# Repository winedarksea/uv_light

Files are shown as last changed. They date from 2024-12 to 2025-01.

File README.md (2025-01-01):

# uv_light
Licence: CERN Open Hardware Licence Version 2 - Strongly Reciprocal

 Custom Sun Lamp / Full Spectrum Lamp
 
 Background writeup [here](https://syllepsis.live/2024/12/31/light-for-health-and-a-custom-sun-lamp/)

A heatsink is important. All 16 leds are too much, unfortunately.

Problem: the comparator circuit for voltage sensing doesn't work properly, and needs a look at.

Minor problem: there's one trace that is bridged by the heatsink here. Using a non conductive thermal pad between the pcb and heatsink solves that problem, or redesign.

Recommendation: add a switch to the UV circuit as well. Also perhaps use larger switches than those specced here if you intend to switch the active lights often.

Designed for:
* QLUV07EYGE
* JE2835 3V N CLASS FAR RED
* Samsung LM302N White, Cool 6500K 
* Samsung LM302N WARM WHT 2700K 1212
* GT PSLR31.13-LUMQ-T1T2-1-150-R18 LED DURIS S5 GREEN 540NM SMD

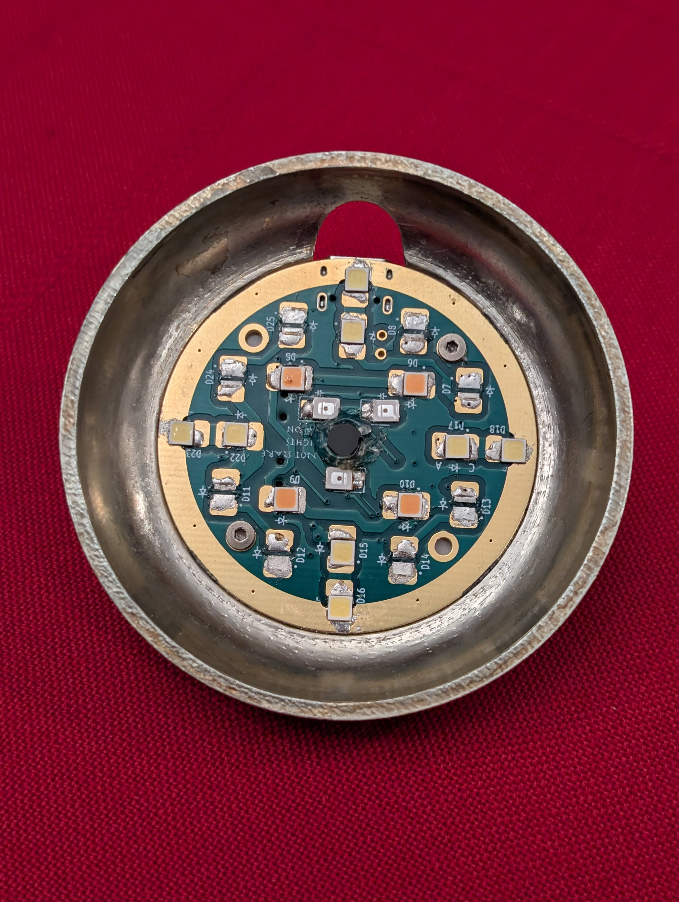
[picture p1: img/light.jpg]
plot


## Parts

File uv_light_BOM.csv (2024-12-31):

Designator | Value | Footprint | Vendor
C1, C2, C3, C4, C5, C6, C7, C8, C9, C10, C11, C12, C13, C14 | 1 uF 50V X5R | Capacitor_SMD:C_0603_1608Metric | C15849
C15 | 10 nF 50V X7R | Capacitor_SMD:C_0402_1005Metric_Pad0.74x0.62mm_HandSolder | C15195
D21 | SM712_SOT23 | Package_TO_SOT_SMD:SOT-23 | C32677
D26 | GI_LED | LED_SMD:LED_0805_2012Metric_Pad1.15x1.40mm_HandSolder | C2297
D27 | RI_LED | LED_SMD:LED_0603_1608Metric_Pad1.05x0.95mm_HandSolder | C2286
J1 | USB_C_Receptacle_USB2.0 | Connector_USB:USB_C_Receptacle_HRO_TYPE-C-31-M-12 | C165948
Q1, Q4, Q5 | AO3401A | Package_TO_SOT_SMD:SOT-23 | C15127
Q2, Q3 | P-Channel DFN-8 | PowerIC:TRANS_AONR21307 | C541711
R1 | 33 | Resistor_SMD:R_0603_1608Metric_Pad0.98x0.95mm_HandSolder | C23140
R2 | 10 | Resistor_SMD:R_0805_2012Metric_Pad1.20x1.40mm_HandSolder | C17415
R3, R11, R12 | 200K | Resistor_SMD:R_0402_1005Metric_Pad0.72x0.64mm_HandSolder | C25764
R4, R6 | 4.53K | Resistor_SMD:R_0603_1608Metric_Pad0.98x0.95mm_HandSolder | C321916
R5 | 10K | Resistor_SMD:R_0603_1608Metric_Pad0.98x0.95mm_HandSolder | C25804
R7 | 180 | Resistor_SMD:R_0603_1608Metric_Pad0.98x0.95mm_HandSolder | C22828
R8, R9, R13, R14 | 680 | Resistor_SMD:R_0805_2012Metric_Pad1.20x1.40mm_HandSolder | C17798
R10 | 2K7 | Resistor_SMD:R_0603_1608Metric_Pad0.98x0.95mm_HandSolder | C13167
SW1, SW2 | SW_SPDT | Button_Switch_SMD:SW_SPDT_PCM12 | C128955
U1 | HUSB238 | Package_DFN_QFN:DFN-10-1EP_3x3mm_P0.5mm_EP1.65x2.38mm | C7471904
U2 | LM393 | Package_SO:SOIC-8_3.9x4.9mm_P1.27mm | C7955
U3 | TL431DBZ | Package_TO_SOT_SMD:SOT-23 | C3113

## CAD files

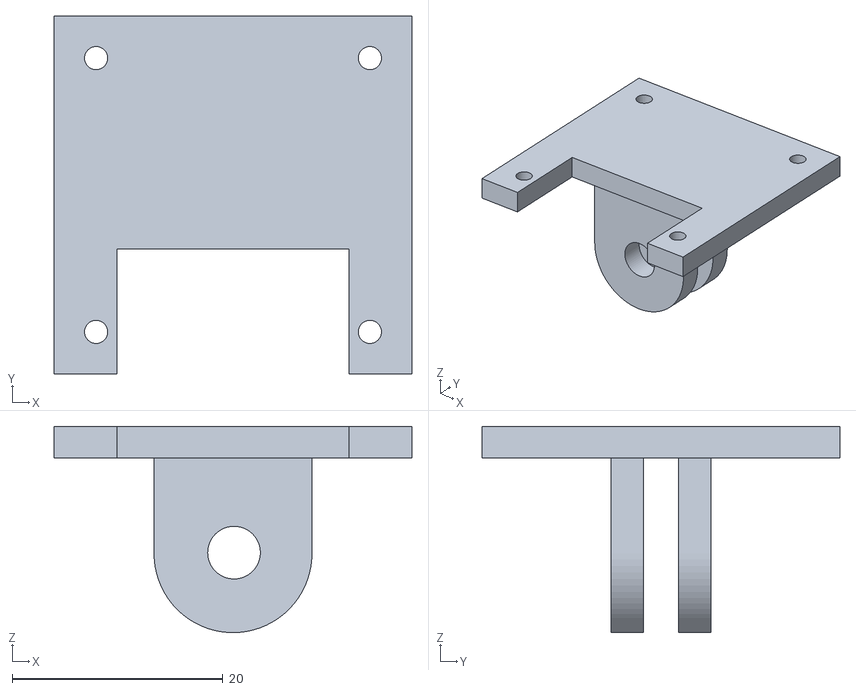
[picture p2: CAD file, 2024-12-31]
3d_files/GoPro mount for Reflector.stl
34.0 x 34.0 x 19.6

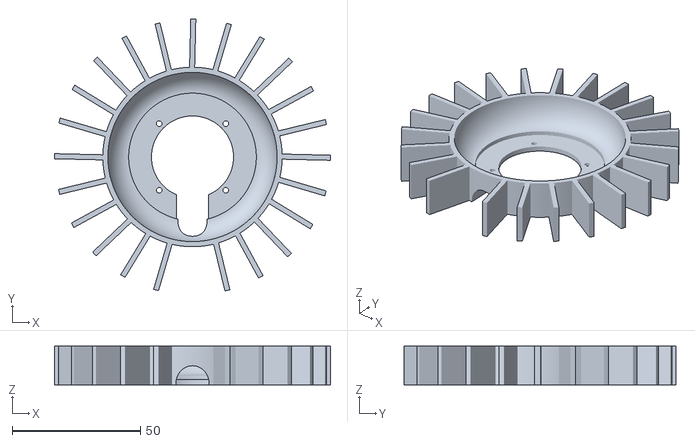
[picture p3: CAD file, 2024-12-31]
3d_files/UV Reflector with fins.stl
107.7 x 106.1 x 15.0

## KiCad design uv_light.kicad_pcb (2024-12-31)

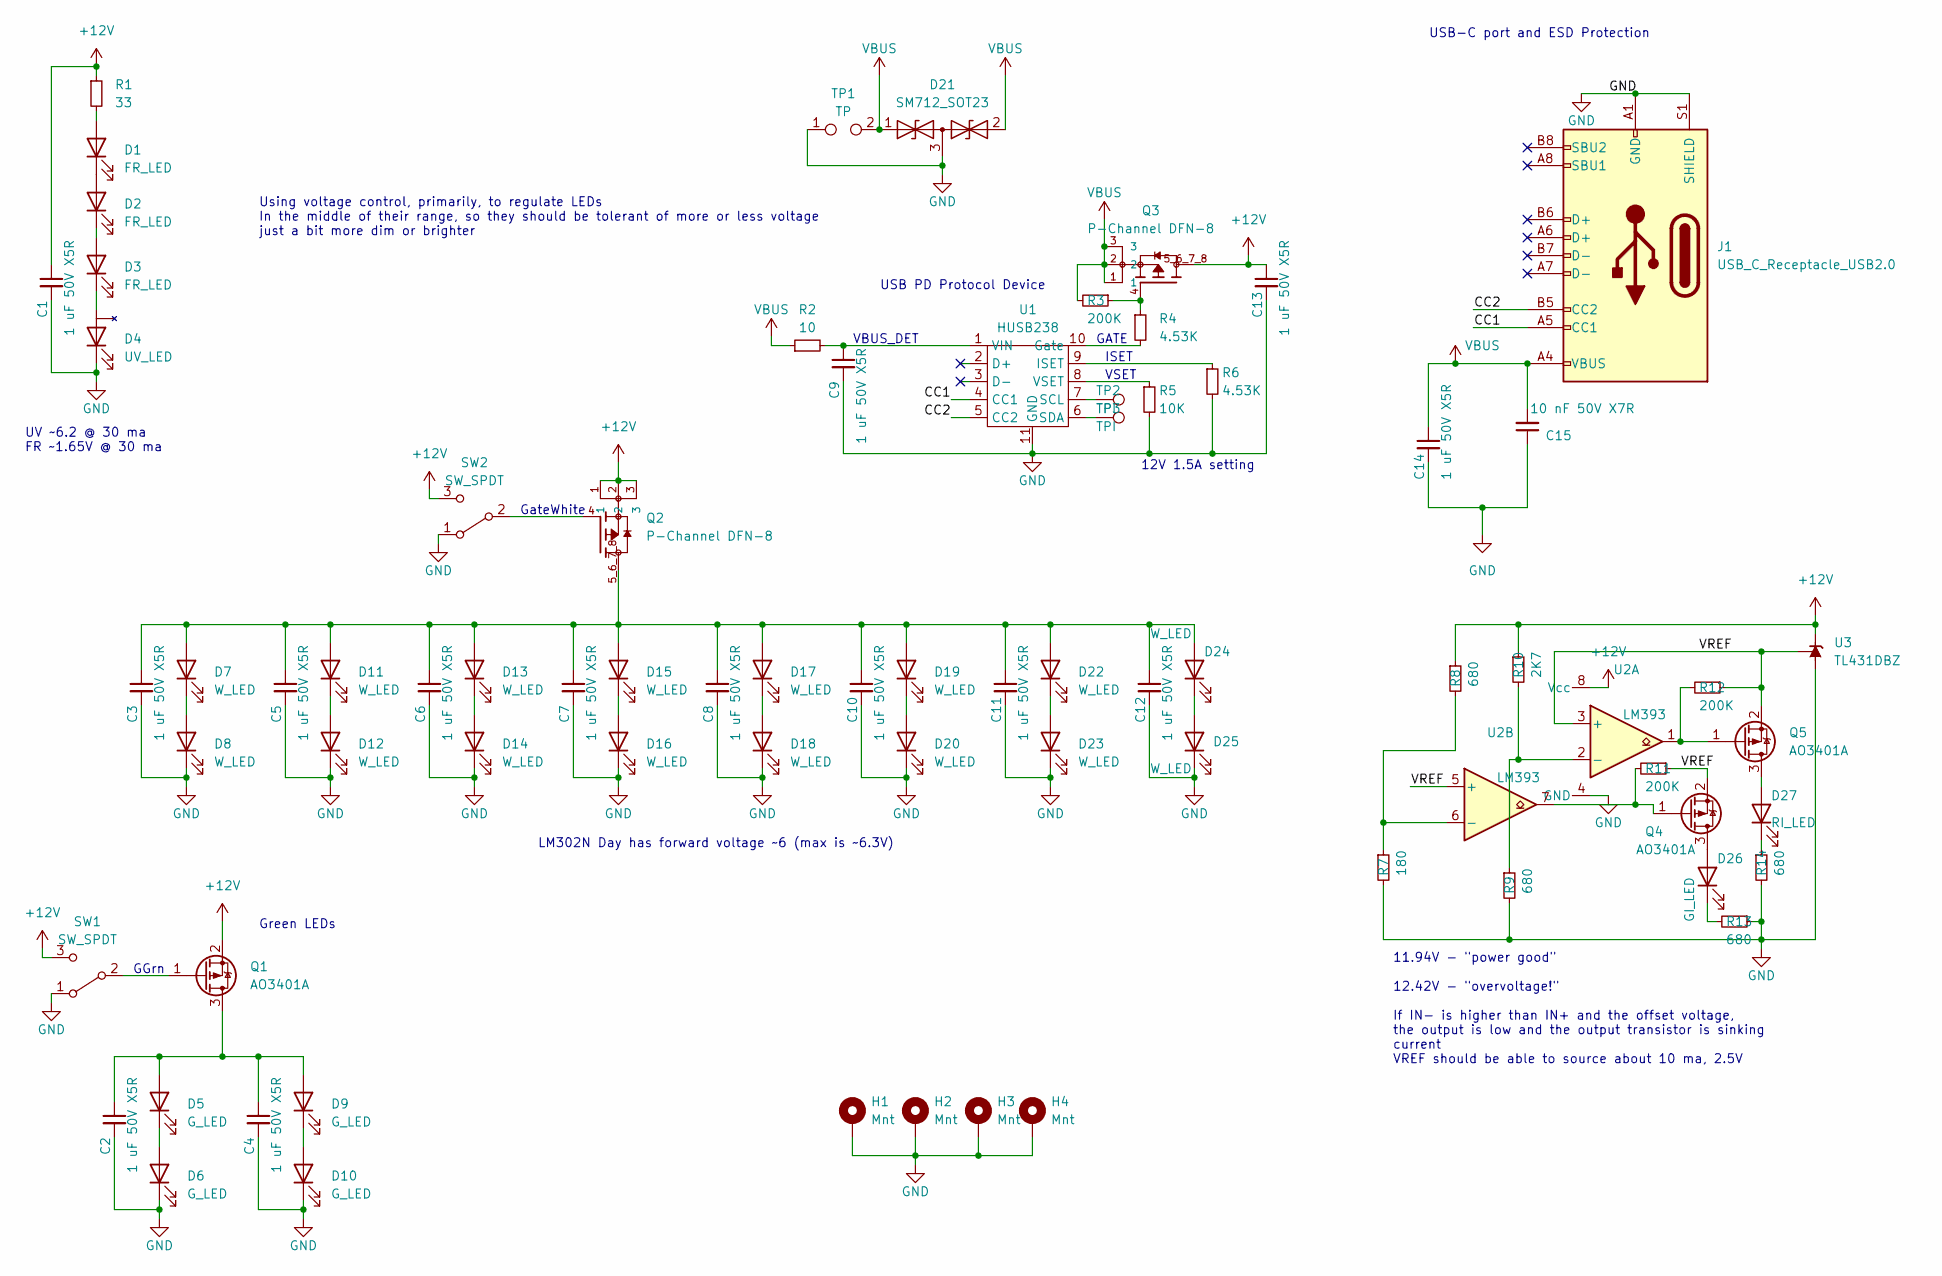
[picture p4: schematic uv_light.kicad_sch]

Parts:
C1, C2, C3, C4, C5, C6, C7, C8, C9, C10, C11, C12, C13, C14: 1 uF 50V X5R; C_0603_1608Metric
C15: 10 nF 50V X7R; C_0402_1005Metric_Pad0.74x0.62mm_HandSolder
D1, D2, D3: FR_LED; LED_PLCC_2835_Handsoldering
D4: UV_LED; LED_Cree-XHP35
D5, D6, D9, D10: G_LED; LED_SMD3030
D7, D8, D11, D12, D13, D14, D15, D16, D17, D18, D19, D20, D22, D23, D24, D25: W_LED; LED_SMD3030
D21: SM712_SOT23; SOT-23
D26: GI_LED; LED_0805_2012Metric_Pad1.15x1.40mm_HandSolder
D27: RI_LED; LED_0603_1608Metric_Pad1.05x0.95mm_HandSolder
H1, H2, H3, H4: Mnt; MountingHole_2.2mm_M2_DIN965_Pad
J1: USB_C_Receptacle_USB2.0; USB_C_Receptacle_HRO_TYPE-C-31-M-12
Q1, Q4, Q5: AO3401A; SOT-23
Q2, Q3: P-Channel DFN-8; TRANS_AONR21307
R1: 33; R_0603_1608Metric_Pad0.98x0.95mm_HandSolder
R2: 10; R_0805_2012Metric_Pad1.20x1.40mm_HandSolder
R3, R11, R12: 200K; R_0402_1005Metric_Pad0.72x0.64mm_HandSolder
R4, R6: 4.53K; R_0603_1608Metric_Pad0.98x0.95mm_HandSolder
R5: 10K; R_0603_1608Metric_Pad0.98x0.95mm_HandSolder
R7: 180; R_0603_1608Metric_Pad0.98x0.95mm_HandSolder
R8, R9, R13, R14: 680; R_0805_2012Metric_Pad1.20x1.40mm_HandSolder
R10: 2K7; R_0603_1608Metric_Pad0.98x0.95mm_HandSolder
SW1, SW2: SW_SPDT; SW_SPDT_PCM12
TP1: TP; TestPoint_2Pads_Pitch2.54mm_Drill0.8mm
TP2, TP3: TPI; TestPoint_Pad_D2.0mm
U1: HUSB238; DFN-10-1EP_3x3mm_P0.5mm_EP1.65x2.38mm
U2: LM393; SOIC-8_3.9x4.9mm_P1.27mm
U3: TL431DBZ; SOT-23

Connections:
+12V: C1.1, C13.1, Q1.2 (S), Q2.1, Q2.2, Q2.3, Q3.5_6_7_8, R1.1, R8.1, R10.1, SW1.3 (C), SW2.3 (C), U2.8 (Vcc), U3.1 (K)
/CC1: J1.A5 (CC1), U1.4 (CC1)
/CC2: J1.B5 (CC2), U1.5 (CC2)
/VREF: Q4.2 (S), Q5.2 (S), R11.1, R12.1, U2.3 (+), U2.5 (+), U3.2 (REF)
GND: C1.2, C2.2, C3.2, C4.2, C5.2, C6.2, C7.2, C8.2, C9.2, C10.2, C11.2, C12.2, C13.2, C14.2, C15.1, D4.1 (K), D6.1 (K), D8.1 (K), D10.1 (K), D12.1 (K), D14.1 (K), D16.1 (K), D18.1 (K), D20.1 (K), D21.3 (common), D23.1 (K), D25.1 (K), H1.1, H2.1, H3.1, H4.1, J1.A1 (GND), J1.A12 (GND), J1.B1 (GND), J1.B12 (GND), J1.S1 (SHIELD), R5.2, R6.2, R7.2, R9.2, R13.1, R14.2, SW1.1 (A), SW2.1 (A), TP1.1, U1.11 (GND), U2.4 (GND), U3.3 (A)
unnamed: D1.2 (A), R1.2
unnamed: D1.1 (K), D2.2 (A)
unnamed: D2.1 (K), D3.2 (A)
unnamed: D3.1 (K), D4.2 (A)
unnamed: C2.1, C4.1, D5.2 (A), D9.2 (A), Q1.3 (D)
unnamed: D5.1 (K), D6.2 (A)
unnamed: D7.1 (K), D8.2 (A)
unnamed: D9.1 (K), D10.2 (A)
unnamed: C3.1, C5.1, C6.1, C7.1, C8.1, C10.1, C11.1, C12.1, D7.2 (A), D11.2 (A), D13.2 (A), D15.2 (A), D17.2 (A), D19.2 (A), D22.2 (A), D24.2 (A), Q2.5_6_7_8
unnamed: D11.1 (K), D12.2 (A)
unnamed: D13.1 (K), D14.2 (A)
unnamed: D15.1 (K), D16.2 (A)
unnamed: D17.1 (K), D18.2 (A)
unnamed: D19.1 (K), D20.2 (A)
unnamed: D22.1 (K), D23.2 (A)
unnamed: D24.1 (K), D25.2 (A)
unnamed: D26.2 (A), Q4.3 (D)
unnamed: D26.1 (K), R13.2
unnamed: D27.2 (A), Q5.3 (D)
unnamed: D27.1 (K), R14.1
unnamed: Q1.1 (G), SW1.2 (B)
unnamed: Q3.4, R3.1, R4.1
unnamed: Q4.1 (G), R11.2, U2.7
unnamed: Q5.1 (G), R12.2, U2.1
unnamed: Q2.4, SW2.2 (B)
unnamed: R4.2, U1.10 (Gate)
unnamed: R6.1, U1.9 (ISET)
unnamed: TP2.1, U1.7 (SCL)
unnamed: TP3.1, U1.6 (SDA)
unnamed: C9.1, R2.2, U1.1 (VIN)
unnamed: R5.1, U1.8 (VSET)
unnamed: R9.1, R10.2, U2.2 (-)
unnamed: R7.1, R8.2, U2.6 (-)
VBUS: C14.1, C15.2, D21.1 (A1), D21.2 (A2), J1.A4 (VBUS), J1.A9 (VBUS), J1.B4 (VBUS), J1.B9 (VBUS), Q3.1, Q3.2, Q3.3, R2.1, R3.2, TP1.2

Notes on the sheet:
GateWhite
UV ~6.2 @ 30 ma FR ~1.65V @ 30 ma
12V 1.5A setting
Using voltage control, primarily, to regulate LEDs In the middle of their range, so they should be tolerant of more or less voltage just a bit more dim or brighter
11.94V - "power good" 12.42V - "overvoltage!" If IN- is higher than IN+ and the offset voltage, the output is low and the output transistor is sinking current VREF should be able to source about 10 ma, 2.5V
ISET
USB PD Protocol Device
Green LEDs
USB-C port and ESD Protection
GGrn
VBUS_DET
LM302N Day has forward voltage ~6 (max is ~6.3V)
VSET
GATE

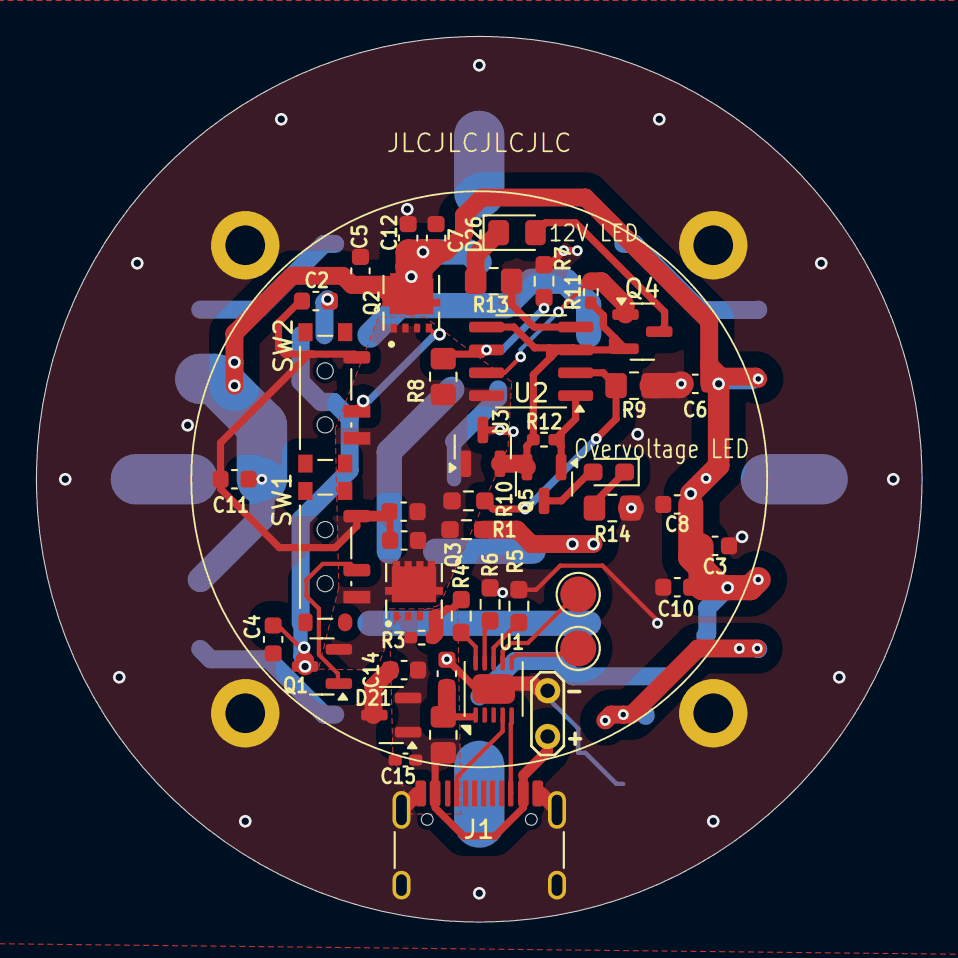
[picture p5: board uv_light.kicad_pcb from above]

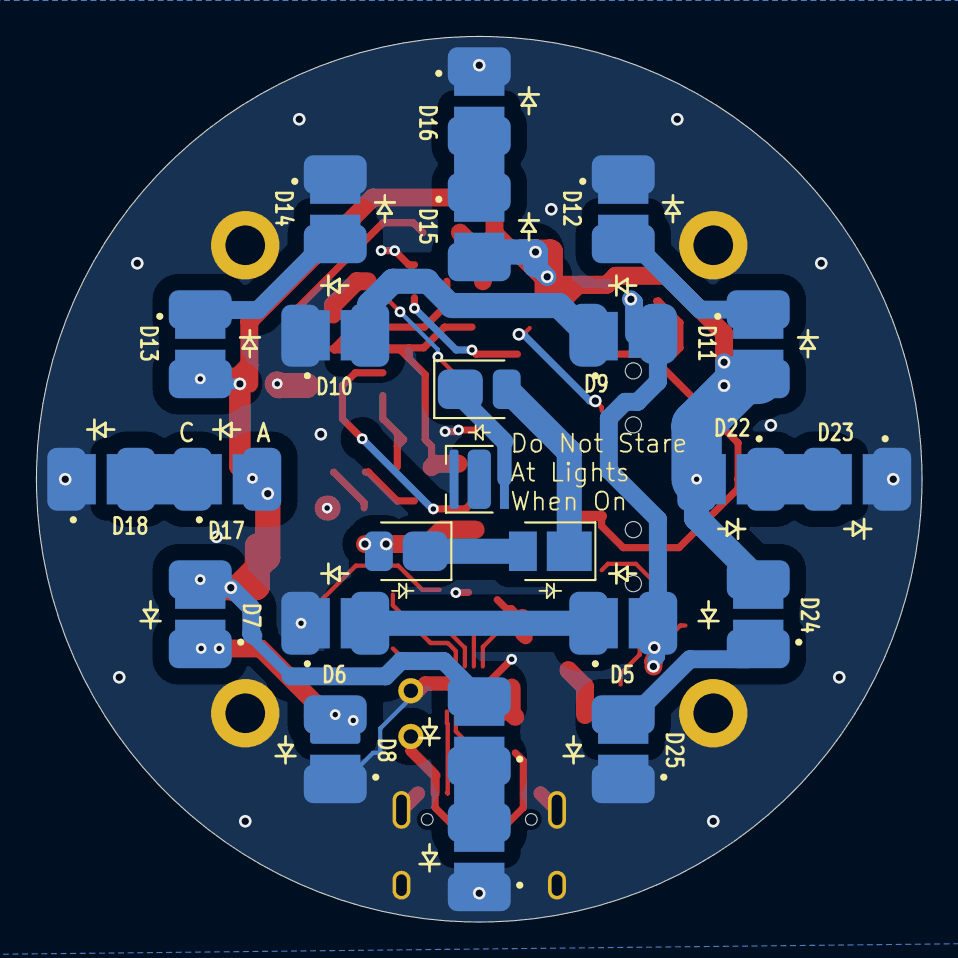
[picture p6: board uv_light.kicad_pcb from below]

Board: 2 copper layers, 49.2 x 49.2 mm, 74 parts (24 on the bottom side), 39 nets.
